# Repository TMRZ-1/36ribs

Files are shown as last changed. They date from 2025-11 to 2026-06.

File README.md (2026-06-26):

# 36ribs

Here you will find everything you need to make your own 36ribs keyboard. It's my first project, so it's not too complicated. 

# UPDATE
Added one led under controller to light it a bit in the middle and updated vial software. Added two new cases, with magnets, normal one just without screws in case and second one with integrated plate that need only magnets. From these three my fav is one that have top mounted plate and magnets in case.

Case with screws:
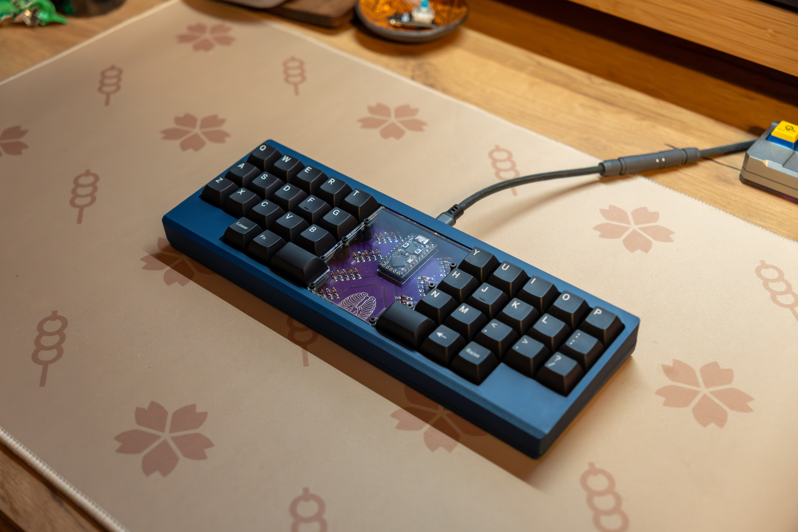
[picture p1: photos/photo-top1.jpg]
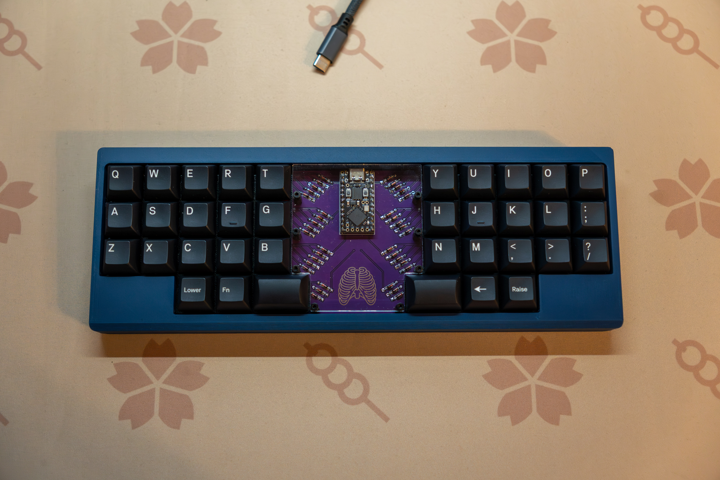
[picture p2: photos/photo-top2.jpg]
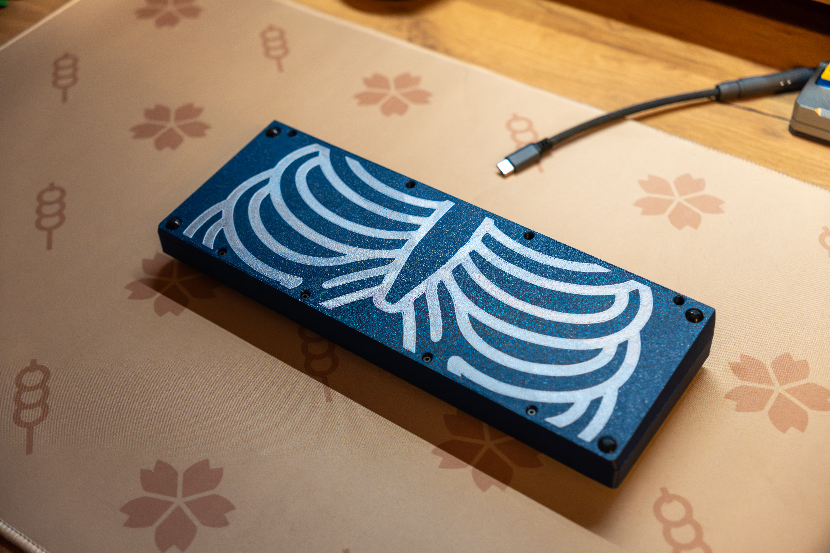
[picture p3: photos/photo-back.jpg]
  

Case with magnets with updated pcb: 
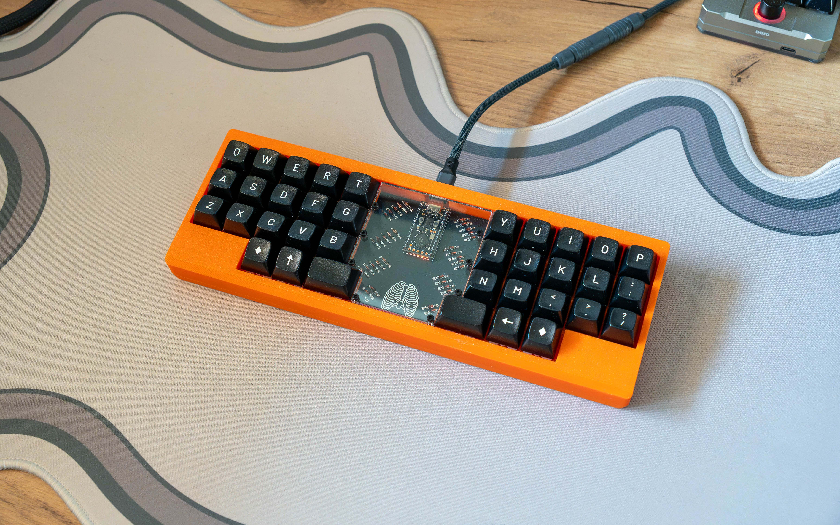
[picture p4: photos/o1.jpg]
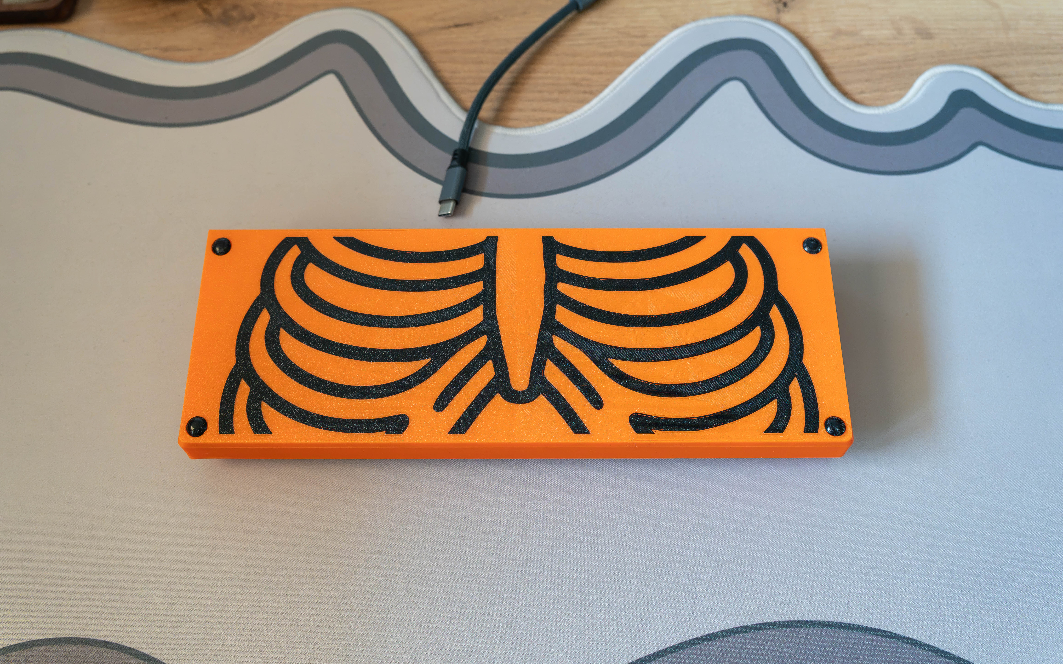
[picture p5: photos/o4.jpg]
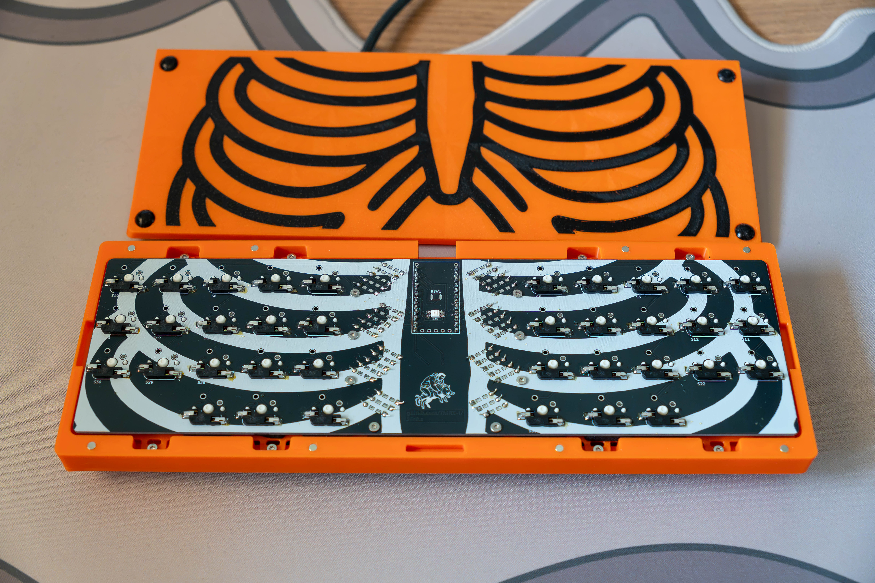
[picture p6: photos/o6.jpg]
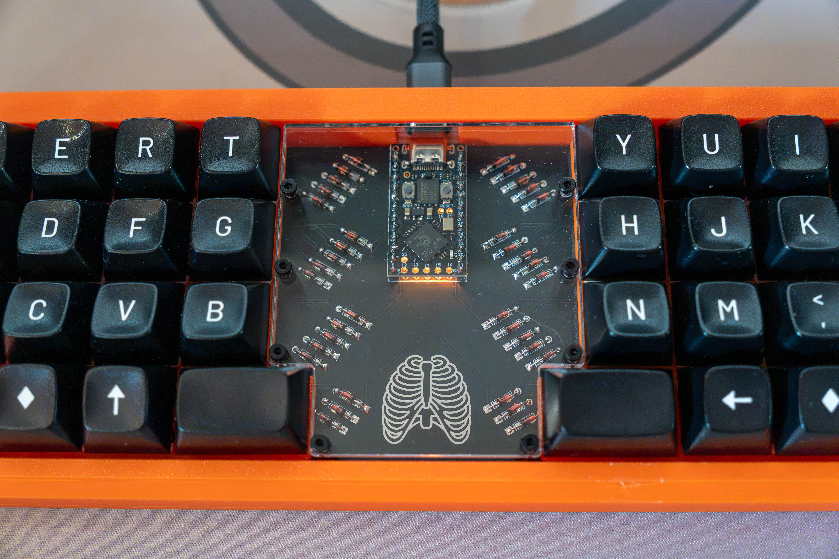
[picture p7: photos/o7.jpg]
   
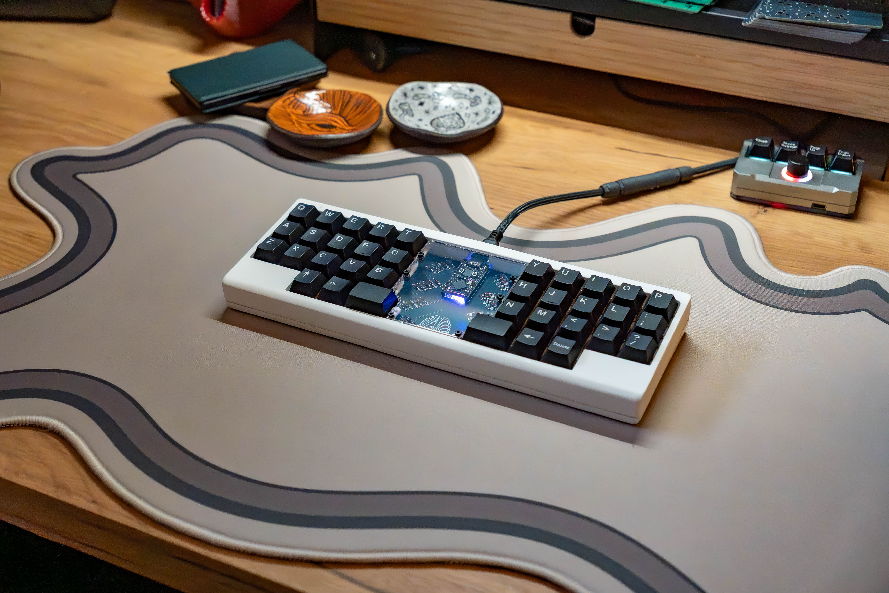
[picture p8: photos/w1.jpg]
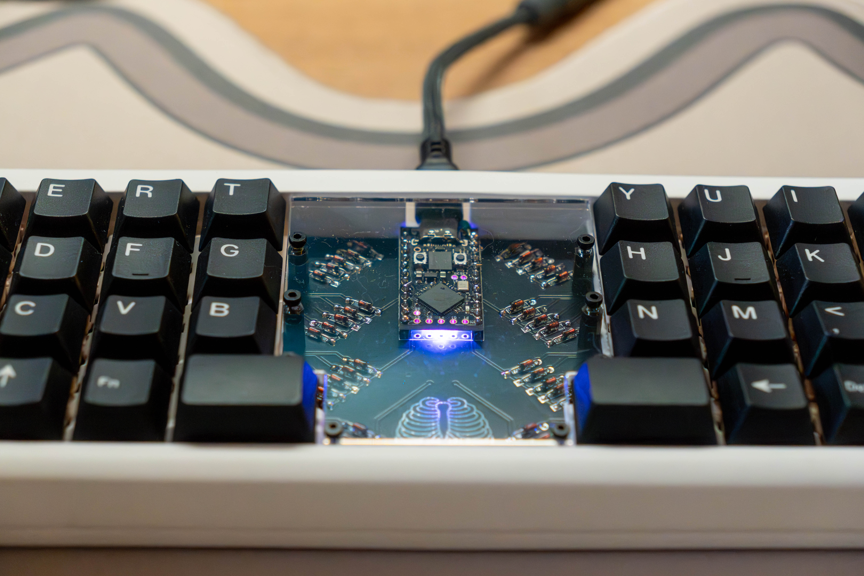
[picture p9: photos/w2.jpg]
 

With that layout you will need 36x keycaps(34x 1u keycaps and for spacebars 2x 1.5u keycaps) and 36x switches.

# BOM for pcb
1. 1x pro micro rp2040 controller
2. 36x 1n4148 or 1n4148w diodes, for better looks take through hole diodes
3. 1x B3U-1000P button for reset
4. 1x SK6812 MINI-E RGB
5. Optional. 36x hotswap sockets, pcb have both, solder and hotswap

# BOM for acrylic cover
1. acrylic cover, I've made 3mm for my build
2. 8x m2 10mm standoffs
3. 16x m2 5mm screws

# BOM for v1 case with screws
1. 16x m2 4x3.2 inserts
2. 16x m2 5mm screws

# BOM for case with magnets
1. 8x m2 4x3.2 inserts
2. 8x m2 5mm screws
3. 16x 3x3 cylinder magnets (I used n42)

# BOM for case with magnets and integrated plate
1. 16x 3x3 cylinder magnets (I used n42)

Diodes should be oriented as shown below.

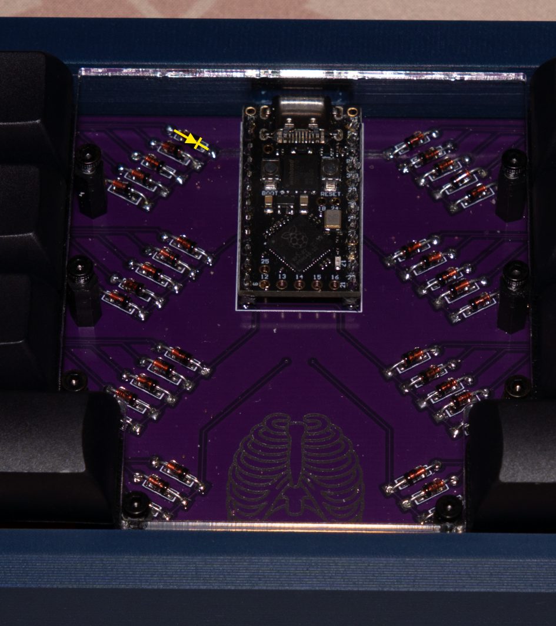
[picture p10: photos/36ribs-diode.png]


The notched leg of the SK6812 MINI-E RGB LED should be in the marked location

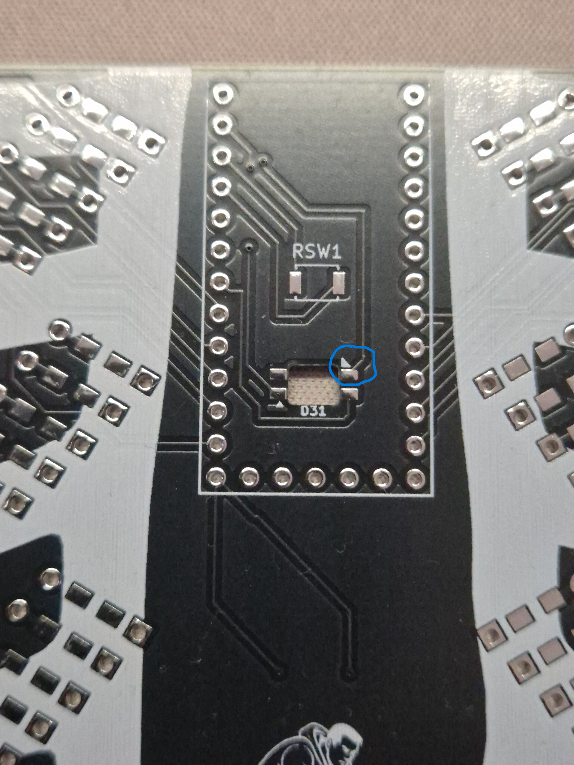
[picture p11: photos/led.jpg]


Inserts for v1 case with screws should be embedded in the marked places.

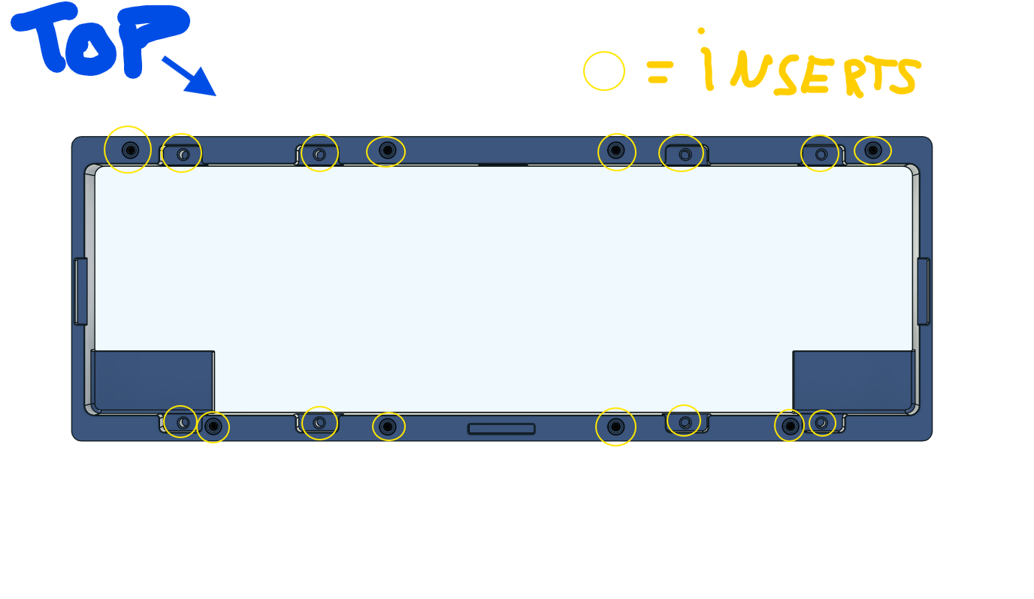
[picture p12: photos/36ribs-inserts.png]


Inserts for magnets case should be embedded in the marked places.

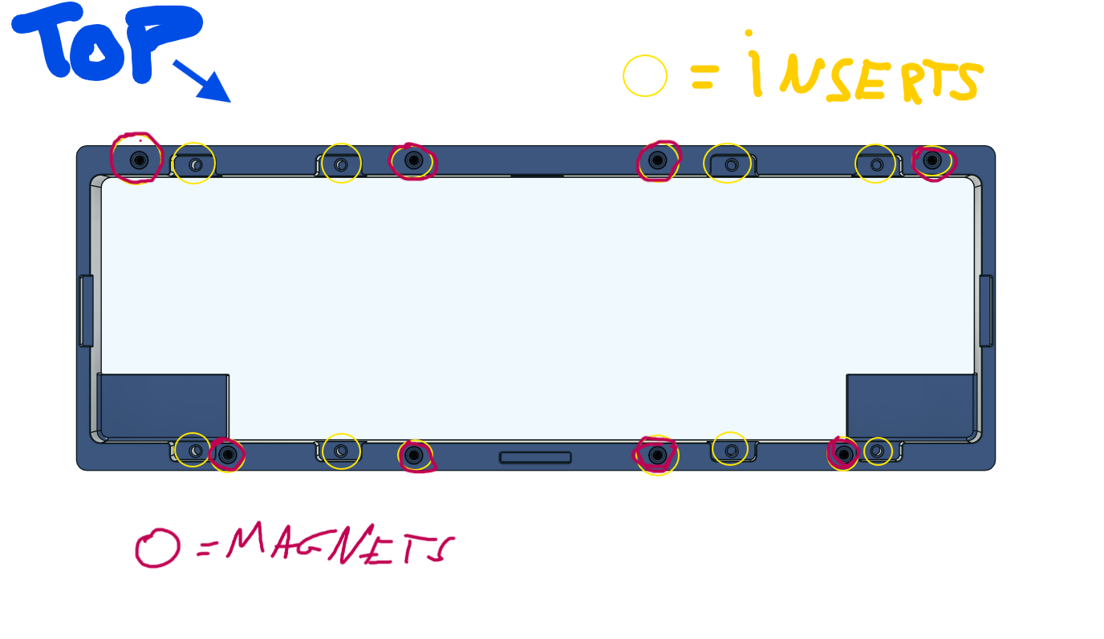
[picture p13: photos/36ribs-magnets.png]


# 36ribs wildlife:

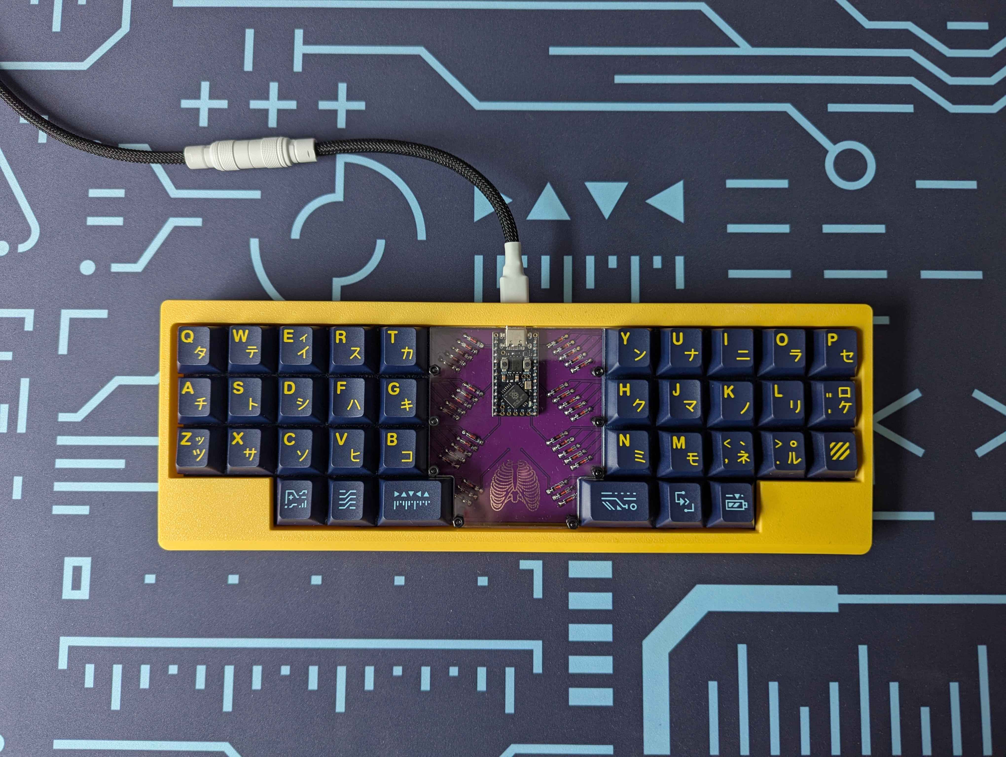
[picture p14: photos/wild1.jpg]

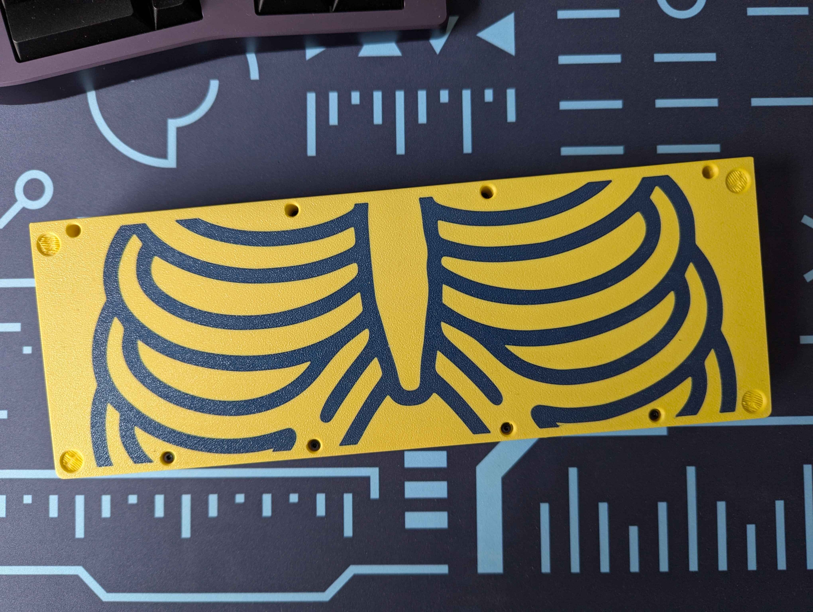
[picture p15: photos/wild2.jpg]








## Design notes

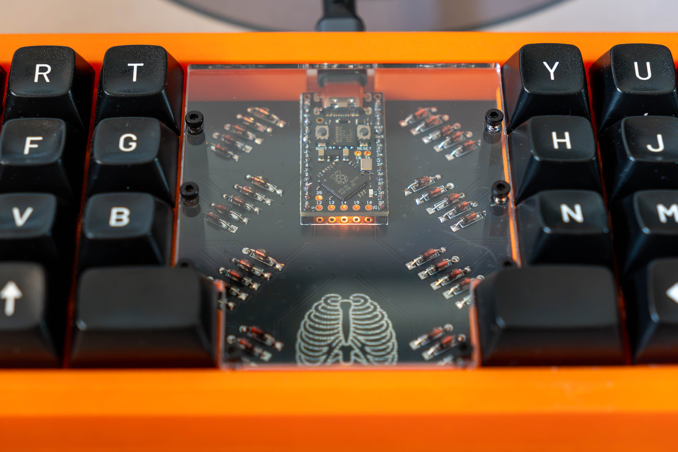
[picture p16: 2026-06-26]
photos/o3.jpg

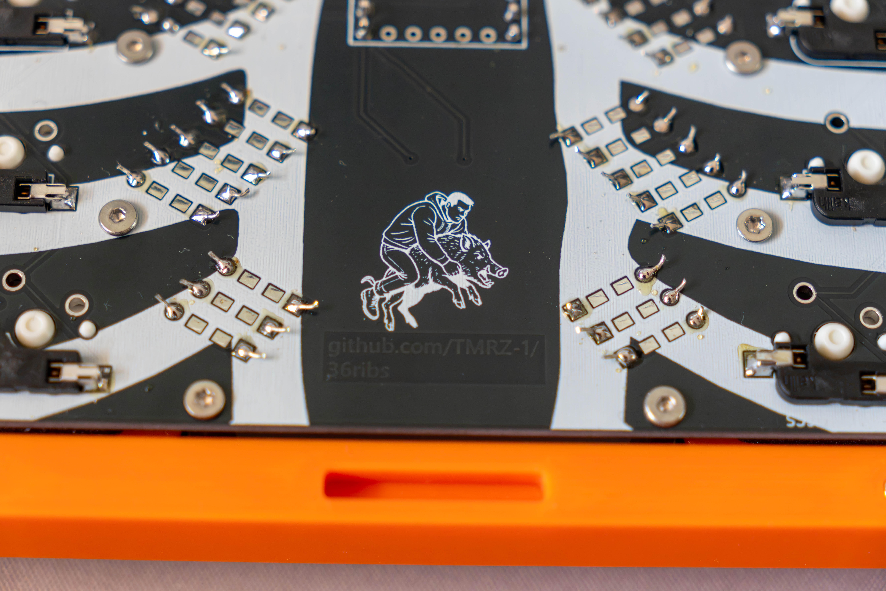
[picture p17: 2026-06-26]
photos/o5.jpg

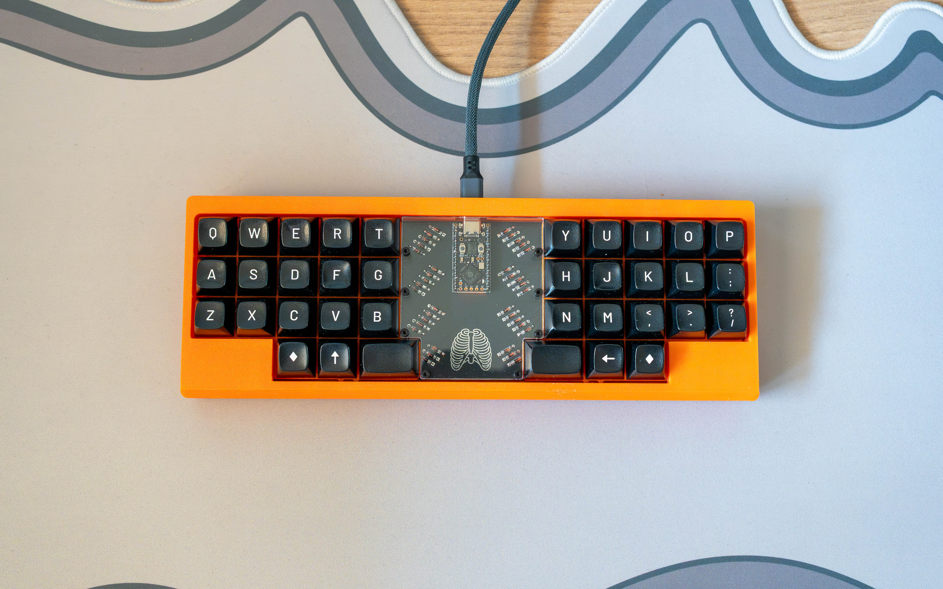
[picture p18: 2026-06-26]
photos/o2.jpg

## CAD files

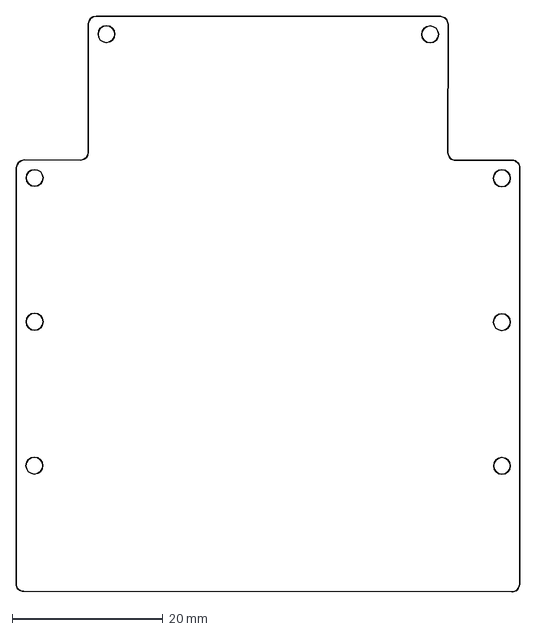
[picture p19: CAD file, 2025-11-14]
case/36ribs-cover.dxf
66.7 x 76.2 mm

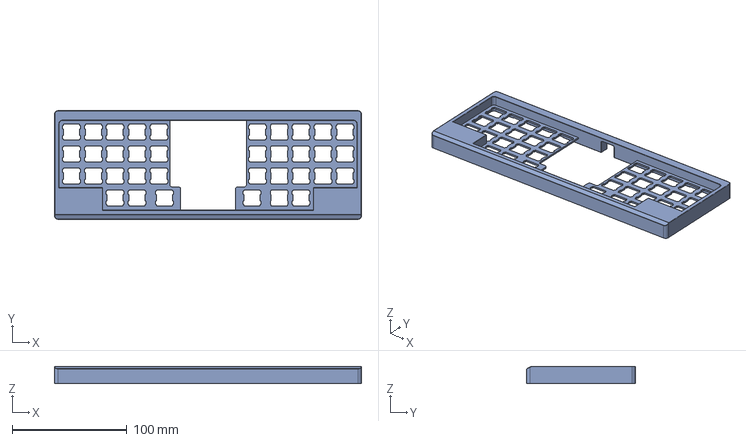
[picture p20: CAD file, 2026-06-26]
case/integrated plate/Top 36ribs magnet.step
267.6 x 94.6 x 15.0 mm

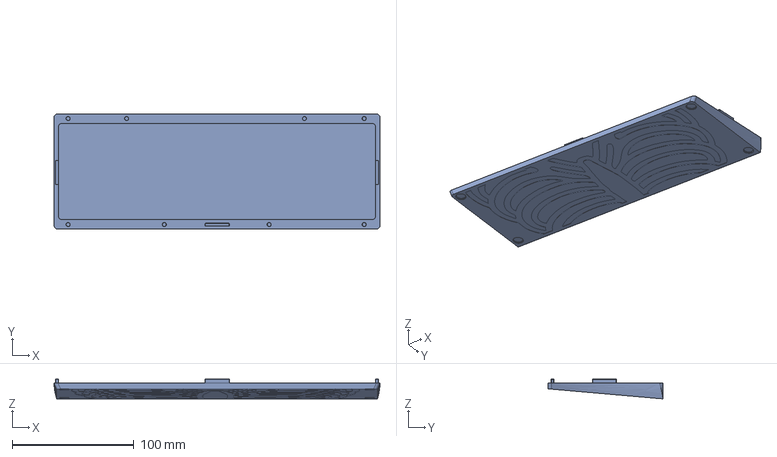
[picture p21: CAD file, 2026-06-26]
case/plate and magnets case/bottom case magnets.step
267.6 x 94.6 x 16.2 mm

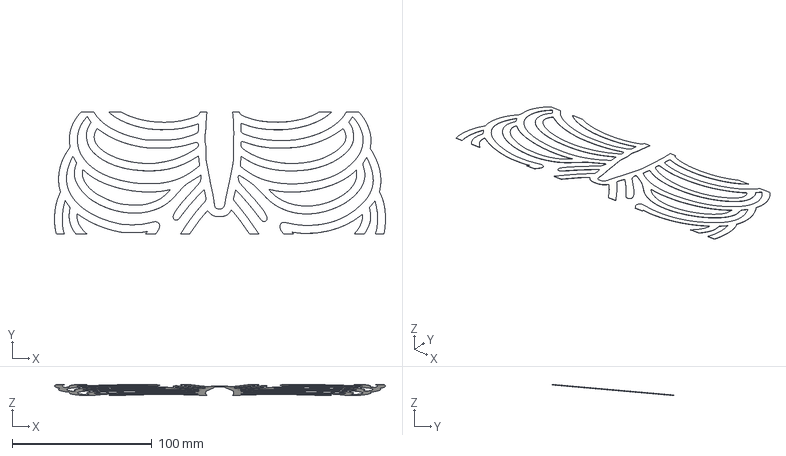
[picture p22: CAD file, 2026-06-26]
case/plate and magnets case/ribs case magnets.step
236.7 x 87.1 x 7.82 mm

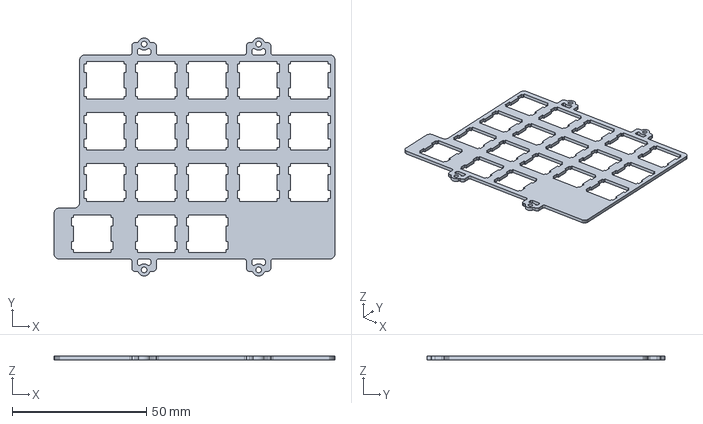
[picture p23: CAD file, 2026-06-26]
case/plate and magnets case/right plate case magnets.step
104.8 x 88.7 x 1.50 mm

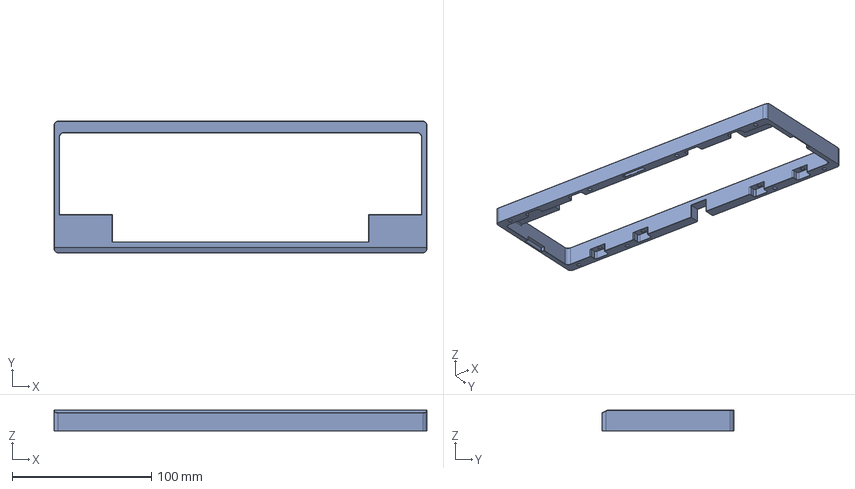
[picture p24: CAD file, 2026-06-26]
case/plate and magnets case/top case magnets.step
267.6 x 94.6 x 15.0 mm

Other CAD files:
case/integrated plate/Bottom 36ribs magnets.step
case/plate and magnets case/left plate case magnets.step

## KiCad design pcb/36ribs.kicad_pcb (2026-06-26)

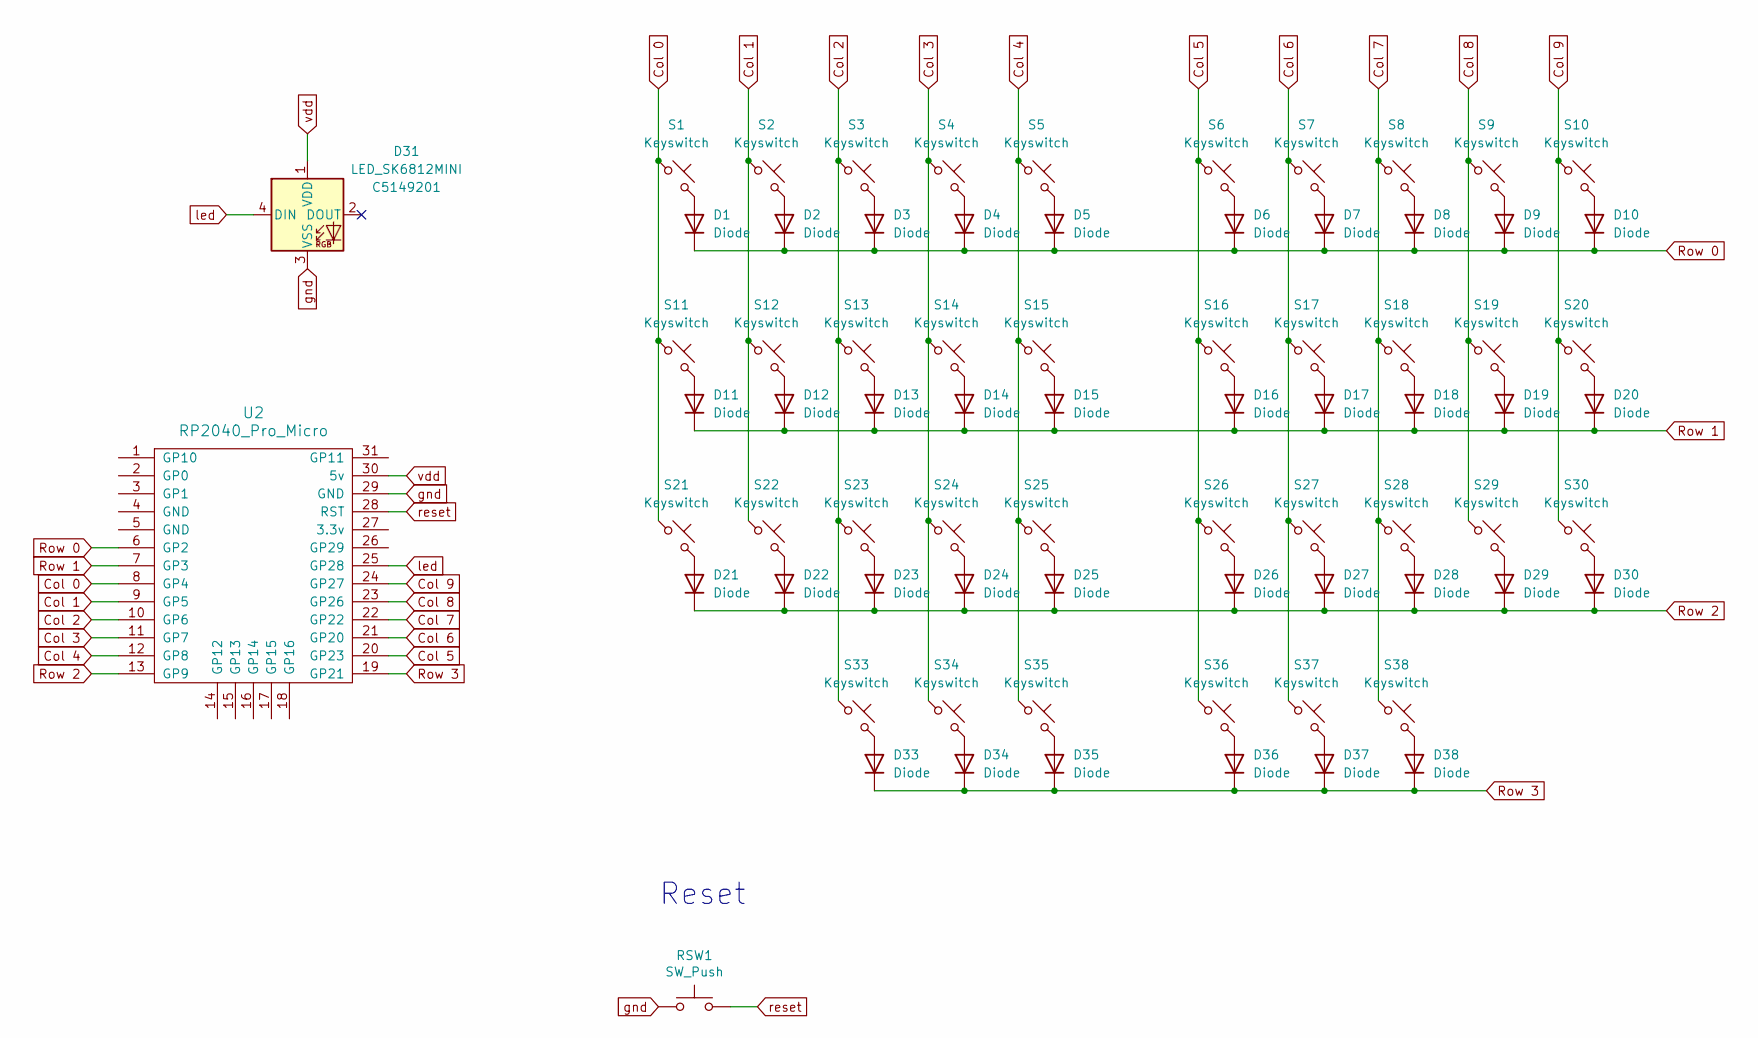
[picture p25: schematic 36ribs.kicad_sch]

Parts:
D1, D2, D3, D4, D5, D6, D7, D8, D9, D10, D11, D12, D13, D14, D15, D16, D17, D18, D19, D20, D21, D22, D23, D24, D25, D26, D27, D28, D29, D30, D33, D34, D35, D36, D37, D38: Diode; Diode-dual
D31: LED_SK6812MINI; SK6812-MINI-E; LCSC C5149201
RSW1: SW_Push; SW_SPST_B3U-1000P
S1, S2, S3, S4, S5, S6, S7, S8, S9, S10, S11, S12, S13, S14, S15, S16, S17, S18, S19, S20, S21, S22, S23, S24, S25, S26, S27, S28, S29, S30, S33, S34, S35, S36, S37, S38: Keyswitch; Kailh_socket_MX_optional
U2: RP2040_Pro_Micro

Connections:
Col 0: S1.1, S11.1, S21.1, U2.8 (GP4)
Col 1: S2.1, S12.1, S22.1, U2.9 (GP5)
Col 2: S3.1, S13.1, S23.1, S33.1, U2.10 (GP6)
Col 3: S4.1, S14.1, S24.1, S34.1, U2.11 (GP7)
Col 4: S5.1, S15.1, S25.1, S35.1, U2.12 (GP8)
Col 5: S6.1, S16.1, S26.1, S36.1, U2.20 (GP23)
Col 6: S7.1, S17.1, S27.1, S37.1, U2.21 (GP20)
Col 7: S8.1, S18.1, S28.1, S38.1, U2.22 (GP22)
Col 8: S9.1, S19.1, S29.1, U2.23 (GP26)
Col 9: S10.1, S20.1, S30.1, U2.24 (GP27)
unnamed: D1.2 (A), S1.2
unnamed: D2.2 (A), S2.2
unnamed: D3.2 (A), S3.2
unnamed: D4.2 (A), S4.2
unnamed: D5.2 (A), S5.2
unnamed: D6.2 (A), S6.2
unnamed: D7.2 (A), S7.2
unnamed: D8.2 (A), S8.2
unnamed: D9.2 (A), S9.2
unnamed: D10.2 (A), S10.2
unnamed: D11.2 (A), S11.2
unnamed: D12.2 (A), S12.2
unnamed: D13.2 (A), S13.2
unnamed: D14.2 (A), S14.2
unnamed: D15.2 (A), S15.2
unnamed: D16.2 (A), S16.2
unnamed: D17.2 (A), S17.2
unnamed: D18.2 (A), S18.2
unnamed: D19.2 (A), S19.2
unnamed: D20.2 (A), S20.2
unnamed: D21.2 (A), S21.2
unnamed: D22.2 (A), S22.2
unnamed: D23.2 (A), S23.2
unnamed: D24.2 (A), S24.2
unnamed: D25.2 (A), S25.2
unnamed: D26.2 (A), S26.2
unnamed: D27.2 (A), S27.2
unnamed: D28.2 (A), S28.2
unnamed: D29.2 (A), S29.2
unnamed: D30.2 (A), S30.2
unnamed: D33.2 (A), S33.2
unnamed: D34.2 (A), S34.2
unnamed: D35.2 (A), S35.2
unnamed: D36.2 (A), S36.2
unnamed: D37.2 (A), S37.2
unnamed: D38.2 (A), S38.2
Row 0: D1.1 (K), D2.1 (K), D3.1 (K), D4.1 (K), D5.1 (K), D6.1 (K), D7.1 (K), D8.1 (K), D9.1 (K), D10.1 (K), U2.6 (GP2)
Row 1: D11.1 (K), D12.1 (K), D13.1 (K), D14.1 (K), D15.1 (K), D16.1 (K), D17.1 (K), D18.1 (K), D19.1 (K), D20.1 (K), U2.7 (GP3)
Row 2: D21.1 (K), D22.1 (K), D23.1 (K), D24.1 (K), D25.1 (K), D26.1 (K), D27.1 (K), D28.1 (K), D29.1 (K), D30.1 (K), U2.13 (GP9)
Row 3: D33.1 (K), D34.1 (K), D35.1 (K), D36.1 (K), D37.1 (K), D38.1 (K), U2.19 (GP21)
gnd: D31.3 (VSS), RSW1.1, U2.29 (GND)
led: D31.4 (DIN), U2.25 (GP28)
reset: RSW1.2, U2.28 (RST)
vdd: D31.1 (VDD), U2.30 (5v)

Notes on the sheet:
Reset

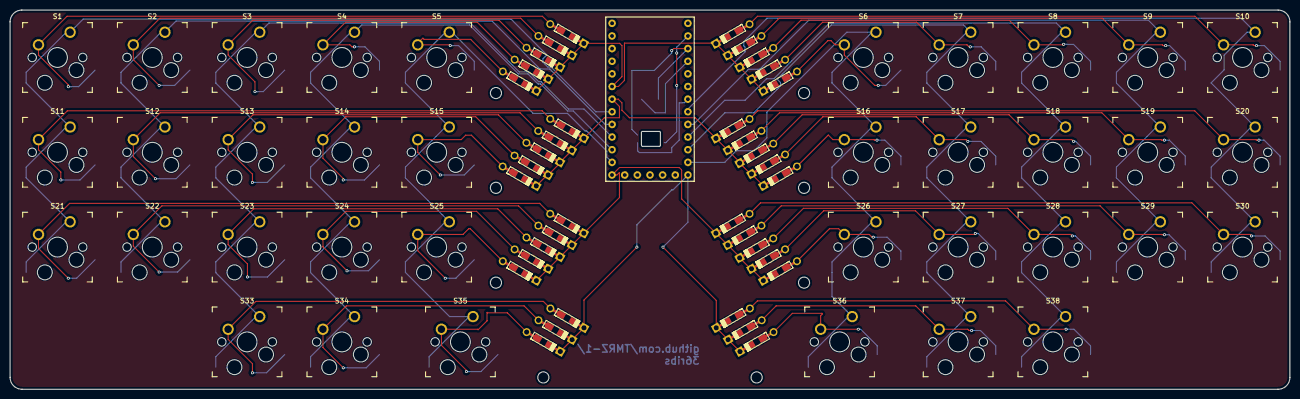
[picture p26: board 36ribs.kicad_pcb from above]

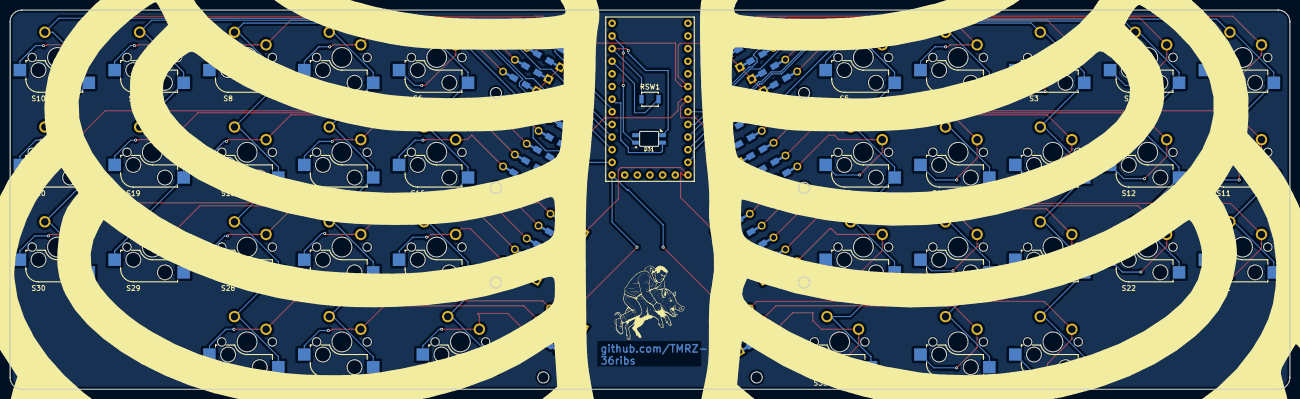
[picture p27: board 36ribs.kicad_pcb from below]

Board: 2 copper layers, 257.2 x 76.2 mm, 75 parts (2 on the bottom side), 54 nets.

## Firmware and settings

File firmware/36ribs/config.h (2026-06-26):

#pragma once

// Dane identyfikacyjne USB
#define VENDOR_ID       0xFEED
#define PRODUCT_ID      0x6060
#define DEVICE_VER      0x0001

// Konfiguracja matrycy
#define MATRIX_ROWS 4
#define MATRIX_COLS 10

// Piny matrycy
#define MATRIX_ROW_PINS { GP2, GP3, GP9, GP21 }
#define MATRIX_COL_PINS { GP4, GP5, GP6, GP7, GP8, GP23, GP20, GP22, GP26, GP27 }

#define DIODE_DIRECTION COL2ROW

// Zezwól Vial na kontrolowanie jasności i efektów rgblight
#define VIAL_RGBLIGHT_ENABLE

// Identyfikator Vial
#define VIAL_KEYBOARD_ID "36ribs"

// Wymagane przez wewnętrzny sterownik ws2812_vendor dla RP2040
#ifndef WS2812_DI_PIN
#    define WS2812_DI_PIN GP28
#endif

// Zabezpieczenie dla ChibiOS system LED pin
#define RP2040_LED_PIN GP28

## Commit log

2025-11-14 Rename 36ribs diode.png to 36ribs-diode.png
2025-11-14 Rename 36ribs inserts.png to 36ribs-inserts.png
2025-11-14 Update README.md
    Updated images and added orientation instructions for diodes and inserts.
2025-11-14 Update README.md
    Updated keycap and switch requirements for clarity.
2026-06-26 Update README.md
    Updated the README to improve formatting and added new BOM sections.
2026-06-26 Update README with case images and BOM changes
    Added images of the keyboard case and updated BOM items.
